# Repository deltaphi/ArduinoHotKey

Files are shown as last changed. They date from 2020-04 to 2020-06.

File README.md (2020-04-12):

# ArduinoHotKey - An Arduino-Based USB Hotkey-Keyboard

This project started because I needed a dedicated button to mute/unmute myself in Voicecalls.
Mute/Unmute functionality is avilable as a Hotkey-Combination, but why pressm ore buttons than necessary?
This project will let you use an Arduino with an Atmega32u4 Processor (e.g., Arduino Pro Micro) to sond arbitrary Key sequences to a USB host device (such as your PC or Mac).
It can send all key sequences that the Arduino Keyboard Library can produce.

## Software

A simple Arduino sketch that can read a number of digital inputs and procude arbitrary key sequences on button press.
Customize the Code to configure the key sequence of your needs.

## Hardware

A simple PCB based around a bunch of Cherry MX PCB-mount switches and an Arduino Pro Micro. Includes Hardware-Deboundinc to be extra-fancy.

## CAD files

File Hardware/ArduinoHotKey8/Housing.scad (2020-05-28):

$fn=50;

wall_thickness = 2; // Should be a multiple of 0.4
fit_tolerance = 0.2;
rotate_angle=-10;

standoff_wall_thickness = 1.6; // Should be a multiple of 0.4.
standoff_inner_diameter = 2.8; // 2,5 when tapping for M3 with extra gear.
standoff_screw_diameter = 6; // Extra space to sink the screw into.
standoff_screw_passthrough_diameter = 3.6; // 3.2 minimum when not tapping.
screw_length = 10;

hole_to_side = 5.08; // Value tested OK

pcb_width = 96.52;
pcb_depth = 77.47;
pcb_thickness = 2;
pcb_side_fit_tolerance = 1;

pcb_front_outer_distance = 5; // 13
pcb_front_inner_distance = pcb_front_outer_distance - wall_thickness;

housing_width = pcb_width + (2*(pcb_side_fit_tolerance + wall_thickness));

housing_depth = pcb_depth + (2*(pcb_side_fit_tolerance + wall_thickness));

pcb_back_inner_distance = 18; // Value tested OK
pcb_back_outer_distance = pcb_back_inner_distance + wall_thickness;

lip_height = pcb_thickness + fit_tolerance;
lip_width = (wall_thickness / 2) - (fit_tolerance / 2);

// Distance from the top
switch_y1 = 33.02; // Value tested OK
switch_y2 = 58.42; // Value tested OK

// Distance from the left
switch_x1 = 10.16; // Value tested OK
switch_x2 = 35.56; // Value tested OK
switch_x3 = 60.96; // Value tested OK
switch_x4 = 86.36; // Value tested OK

// Standoffs

// * Dimenstions
standoff_outer_diameter = standoff_inner_diameter + (2*standoff_wall_thickness);
standoff_outer_screw_diameter = standoff_screw_diameter + (2*standoff_wall_thickness);
standoff_screwhole_diameter = standoff_screw_passthrough_diameter + (2*standoff_wall_thickness);

// * locations in top and bottom
standoff_x1 = wall_thickness + pcb_side_fit_tolerance + hole_to_side;
standoff_x2 = wall_thickness + pcb_side_fit_tolerance + pcb_depth - hole_to_side;

standoff_y1 = wall_thickness + pcb_side_fit_tolerance + hole_to_side;
standoff_y2 = wall_thickness + pcb_side_fit_tolerance + pcb_width - hole_to_side;

// * Module in the bottom case
module standoff_bottom(x,y) {
   
    // Leave 1mm space in the top screw holes
    standoff_bottom_screw_length = screw_length - pcb_thickness - pcb_front_outer_distance + 1;
    standoff_screw_head_height = pcb_back_inner_distance - standoff_bottom_screw_length;
   
    difference() {
        // Solid part
        union() {
            // Screw head part. Should leave standoff_bottom_screw_length - wall_thickness for the following thin part.
            translate([x, y ,0]) cylinder(h=standoff_screw_head_height + wall_thickness,d=standoff_outer_screw_diameter);
            // Screw part
            translate([x, y ,0]) cylinder(h=pcb_back_outer_distance,d=standoff_screwhole_diameter);
        }
       
        // Take away the holes
       
        // Screw head hole part.
        translate([x, y ,-0.1]) cylinder(h=standoff_screw_head_height,d=standoff_screw_diameter);
       
        // Screw hole part
        translate([x, y ,-0.1]) cylinder(h=pcb_back_outer_distance+1,d=standoff_screw_passthrough_diameter);
    }
}

// * Module in the top case
module standoff_top(x,y,height) {
    difference() {
        translate([x, y ,0]) cylinder(h=height,d=standoff_outer_diameter);
        translate([x, y ,-0.1]) cylinder(h=height+1,d=standoff_inner_diameter);
    }
}






// Basic Bottom
module bottomcase() {
difference() {
    union() {
        difference() {
    
            union() {
                // Main wall
                rotate(a=rotate_angle,v=[0,1,0]) cube([housing_depth, housing_width, pcb_back_outer_distance]);
                    
                // Inner lip
                rotate(a=rotate_angle,v=[0,1,0])translate([lip_width, lip_width, 0]) cube([housing_depth - 2*lip_width, housing_width - 2*lip_width, pcb_back_outer_distance+lip_height]);
                
            }
                
            // Inner space
            rotate(a=rotate_angle,v=[0,1,0])translate([wall_thickness,wall_thickness,wall_thickness])
            cube([pcb_depth + (2*pcb_side_fit_tolerance), pcb_width + (2*pcb_side_fit_tolerance),pcb_back_inner_distance+lip_height+1]);
               
            // Hole for USB wire
            rotate(a=rotate_angle,v=[0,1,0])translate([62+wall_thickness,0,10+wall_thickness])
            rotate([90,90,0])
            cylinder(h=wall_thickness*3, d=12, center=true);
    
            rotate(a=rotate_angle,v=[0,1,0])translate([62+wall_thickness,0,18+wall_thickness])
            cube([12,wall_thickness*3,12+lip_height], center = true);
               
    
        }
        // add Standoffs
        rotate(a=rotate_angle,v=[0,1,0])standoff_bottom(standoff_x1, standoff_y1);
        rotate(a=rotate_angle,v=[0,1,0])standoff_bottom(standoff_x2, standoff_y1);
        rotate(a=rotate_angle,v=[0,1,0])standoff_bottom(standoff_x1, standoff_y2);
        rotate(a=rotate_angle,v=[0,1,0])standoff_bottom(standoff_x2, standoff_y2);
        //add bottom layer
        translate([0,0,-1]) cube([housing_depth, housing_width, pcb_back_outer_distance-7]);
    }
    translate([-10,-10,-2]) cube([housing_depth+20, housing_width+20, pcb_back_outer_distance-7]);
    rotate(a=rotate_angle,v=[0,1,0]) translate([-10,-10,-
    5]) cube([housing_depth+20, housing_width+20, 5]);
            // add holes from the bottom
            rotate(a=rotate_angle,v=[0,1,0])translate([standoff_x1, standoff_y1 ,-0.1]) cylinder(d=standoff_screw_diameter, h=10+wall_thickness);
            rotate(a=rotate_angle,v=[0,1,0])translate([standoff_x2, standoff_y1 ,-0.1]) cylinder(d=standoff_screw_diameter, h=10+wall_thickness);
            rotate(a=rotate_angle,v=[0,1,0])translate([standoff_x1, standoff_y2 ,-0.1]) cylinder(d=standoff_screw_diameter, h=10+wall_thickness);
            rotate(a=rotate_angle,v=[0,1,0])translate([standoff_x2, standoff_y2 ,-0.1]) cylinder(d=standoff_screw_diameter, h=10+wall_thickness);
    }
}



// Solid switch cube. Can be used to subtract from cubes to punch correct-sized holes.
// Designed so that the center plane represents the top of the case.
// Adds a recess so that the plate thickness around the switch is limited.
module switch() {
    switch_hole_side = 14;// Value tested correctly for Cherry MX
    switch_plate_thickness = 1.5;
   
    spacer_side = switch_hole_side + 2; // 1mm all round
   
   
    translate([-switch_hole_side/2,-switch_hole_side/2,-1]) cube([switch_hole_side, switch_hole_side, wall_thickness+2]);
    translate([-spacer_side/2,-spacer_side/2,switch_plate_thickness]) cube([spacer_side,spacer_side,wall_thickness+2]);
}

// switch();

module switcharray() {
    translate([switch_y1, switch_x1, 0]) switch();
    translate([switch_y1, switch_x2, 0]) switch();
    translate([switch_y1, switch_x3, 0]) switch();
    translate([switch_y1, switch_x4, 0]) switch();
           
    translate([switch_y2, switch_x1, 0]) switch();
    translate([switch_y2, switch_x2, 0]) switch();
    translate([switch_y2, switch_x3, 0]) switch();
    translate([switch_y2, switch_x4, 0]) switch();
}

// Basic top
module topcase() {

    difference() {

        // Main wall with added height for lip
        cube([housing_depth, housing_width, pcb_front_outer_distance + lip_height]);
           
        // Carve out interior
        translate([wall_thickness, wall_thickness, wall_thickness])
        cube([pcb_depth + (2*pcb_side_fit_tolerance), pcb_width + (2*pcb_side_fit_tolerance), pcb_front_inner_distance+2]);

        // Carve out lip
        translate([lip_width, lip_width, pcb_front_outer_distance])
        cube([housing_depth - 2*lip_width, housing_width - 2*lip_width, pcb_front_inner_distance+2]);

        // Carve out switch holes
        translate([wall_thickness+pcb_side_fit_tolerance, wall_thickness+pcb_side_fit_tolerance, 0]) switcharray();
    }

    // Standoffs
    translate([0,0,wall_thickness-0.1]) standoff_top(standoff_x1, standoff_y1, pcb_front_inner_distance+0.1);
    translate([0,0,wall_thickness-0.1]) standoff_top(standoff_x2, standoff_y1, pcb_front_inner_distance+0.1);
    translate([0,0,wall_thickness-0.1]) standoff_top(standoff_x1, standoff_y2, pcb_front_inner_distance+0.1);
    translate([0,0,wall_thickness-0.1]) standoff_top(standoff_x2, standoff_y2, pcb_front_inner_distance+0.1);
}

module all() {
    translate([-100,0,0]) bottomcase();
    translate([20,0,0]) topcase();
}

all();

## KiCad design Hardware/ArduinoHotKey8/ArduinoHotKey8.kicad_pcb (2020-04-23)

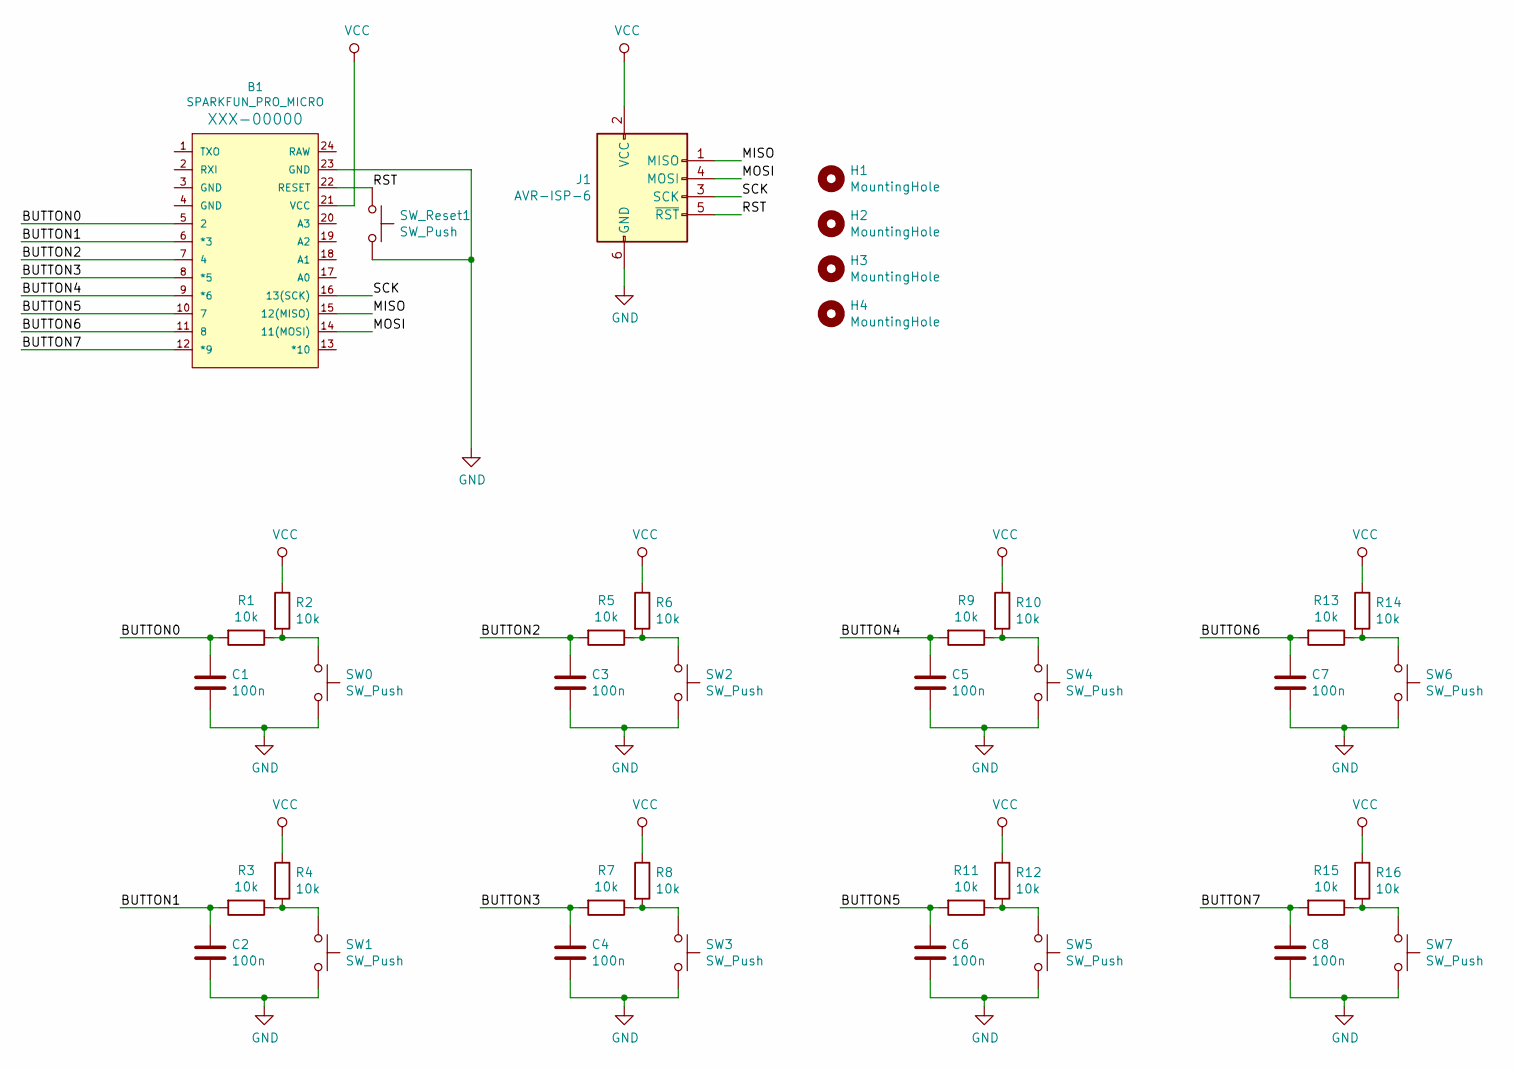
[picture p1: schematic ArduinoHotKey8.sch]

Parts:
B1: SPARKFUN_PRO_MICRO
C1, C2, C3, C4, C5, C6, C7, C8: 100n; C_Disc_D3.0mm_W1.6mm_P2.50mm
H1, H2, H3, H4: MountingHole; MountingHole_3.2mm_M3
J1: AVR-ISP-6; IDC-Header_2x03_P2.54mm_Vertical
R1, R2, R3, R4, R5, R6, R7, R8, R9, R10, R11, R12, R13, R14, R15, R16: 10k; R_Axial_DIN0207_L6.3mm_D2.5mm_P10.16mm_Horizontal
SW0, SW1, SW2, SW3, SW4, SW5, SW6, SW7: SW_Push; SW_Cherry_MX_1.00u_PCB
SW_Reset1: SW_Push; SW_PUSH_6mm

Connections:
/BUTTON0: B1.5 (2), C1.1, R1.2
/BUTTON1: B1.6 (*3), C2.1, R3.2
/BUTTON2: B1.7 (4), C3.1, R5.2
/BUTTON3: B1.8 (*5), C4.1, R7.2
/BUTTON4: B1.9 (*6), C5.1, R9.2
/BUTTON5: B1.10 (7), C6.1, R11.2
/BUTTON6: B1.11 (8), C7.1, R13.2
/BUTTON7: B1.12 (*9), C8.1, R15.2
/MISO: B1.15 (12(MISO)), J1.1 (MISO)
/MOSI: B1.14 (11(MOSI)), J1.4 (MOSI)
/RST: B1.22 (RESET), J1.5 (~RST), SW_Reset1.1
/SCK: B1.16 (13(SCK)), J1.3 (SCK)
GND: B1.23 (GND), C1.2, C2.2, C3.2, C4.2, C5.2, C6.2, C7.2, C8.2, J1.6 (GND), SW0.2, SW1.2, SW2.2, SW3.2, SW4.2, SW5.2, SW6.2, SW7.2, SW_Reset1.2
unnamed: R1.1, R2.2, SW0.1
unnamed: R3.1, R4.2, SW1.1
unnamed: R5.1, R6.2, SW2.1
unnamed: R7.1, R8.2, SW3.1
unnamed: R9.1, R10.2, SW4.1
unnamed: R11.1, R12.2, SW5.1
unnamed: R13.1, R14.2, SW6.1
unnamed: R15.1, R16.2, SW7.1
VCC: B1.21 (VCC), J1.2 (VCC), R2.1, R4.1, R6.1, R8.1, R10.1, R12.1, R14.1, R16.1

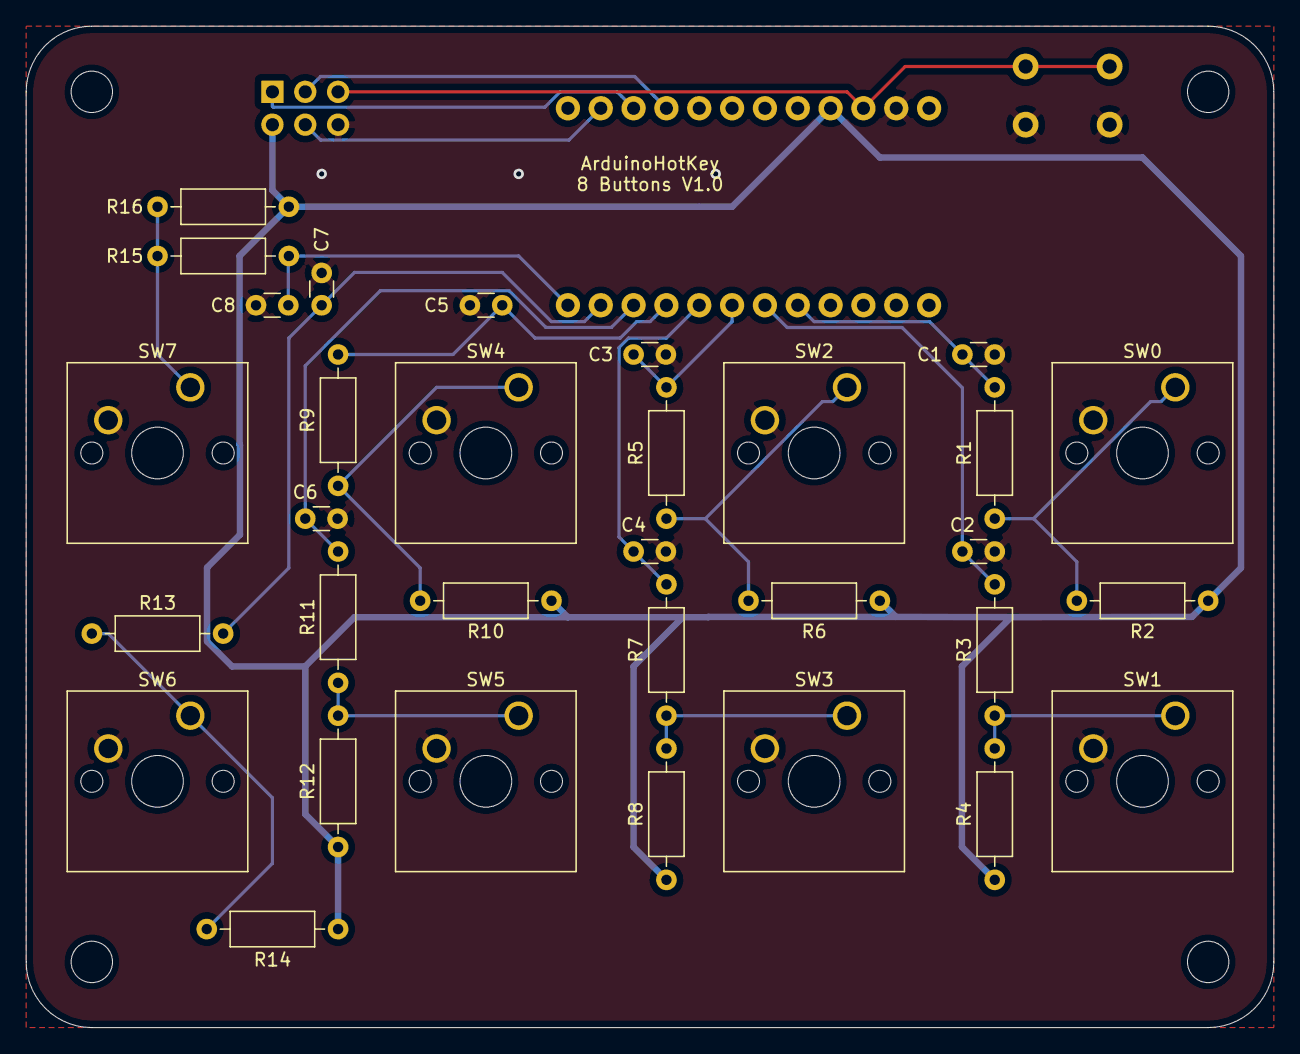
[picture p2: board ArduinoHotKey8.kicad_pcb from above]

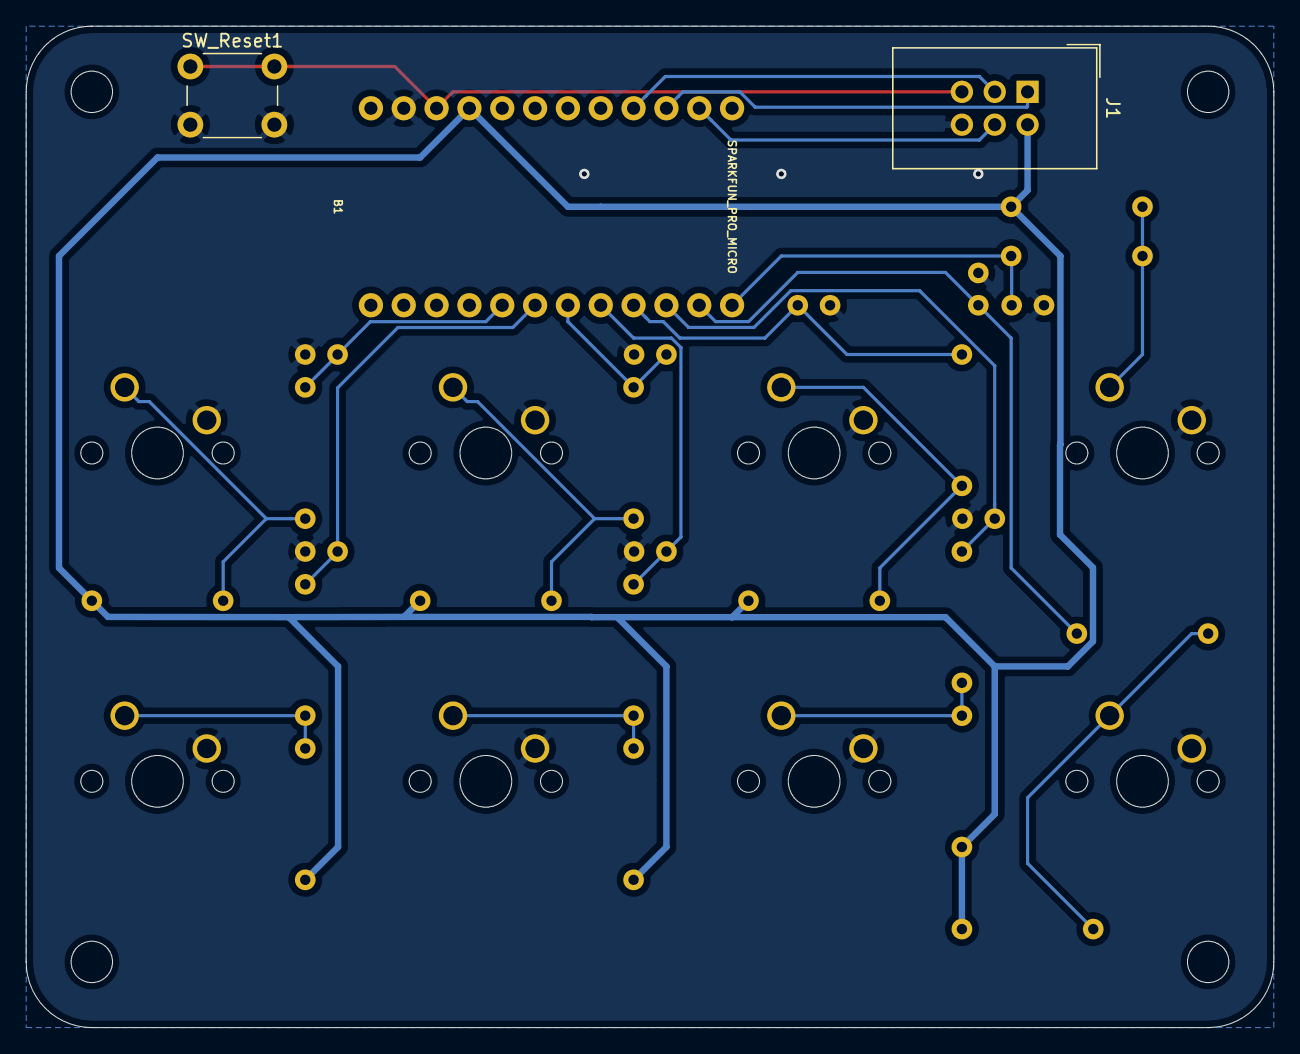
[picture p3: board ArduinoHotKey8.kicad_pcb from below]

Board: 2 copper layers, 96.5 x 77.5 mm, 39 parts (3 on the bottom side), 22 nets.

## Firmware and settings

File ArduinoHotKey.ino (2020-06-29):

/*
 * ArduinoHotKey Sketch.
 * 
 * Hotkey-Keyboard for up to 8 Buttons on an Arduino Pro Nano (Atmega32)
 * 
 * Requires the HID-Project library:
 *  https://www.arduinolibraries.info/libraries/hid-project
 *  
 */

#include "HID-Project.h"

// -------------------------
// Tweak your paramters here
// -------------------------

#define NUM_BUTTONS (8)
#define BUTTON_INDEX_OFFSET (2)
#define BUTTON_DISTANCE (1)

#define BUTTON_PRESSED(x) (x == LOW)

#define USE_SERIAL_DEBUG (0)

// ----------------------------------------------------------
// Stop Tweaking paramters here and continue tweaking actions
// below.
// ----------------------------------------------------------


uint8_t buttonState[NUM_BUTTONS];

constexpr uint8_t buttonIndexToPin(const uint8_t buttonIndex) {
  return BUTTON_INDEX_OFFSET + (BUTTON_DISTANCE * buttonIndex);
}

void setup() {
#if (USE_SERIAL_DEBUG == 1)
  Serial.begin(115200);
  Serial.println("ArduinoHotKey ready.");
#endif
  
  // Start Keyboard library
  Consumer.begin(); // Media Keys
  Keyboard.begin(); // 'regular' Boot Keyboard

  // Configure all IO pins.
  for (uint8_t i = 0; i < NUM_BUTTONS; ++i) {
    buttonState[i] = HIGH;
    pinMode(buttonIndexToPin(i), INPUT);
  }

}

void releaseAllWithDelay() {
  delay(100);
  Keyboard.releaseAll();
}

void singleButton(uint8_t keyValue, uint8_t keyCode) {
  if (BUTTON_PRESSED(keyValue)) {
    Keyboard.press(keyCode);
  } else {
    Keyboard.release(keyCode);
  }
}

void singleButtonConsumer(uint8_t keyValue, uint8_t keyCode) {
  if (BUTTON_PRESSED(keyValue)) {
    Consumer.press(keyCode);
  } else {
    Consumer.release(keyCode);
  }
}

/**
 * \brief Add processing for actual button presses here.
 * \param buttonIndex The number of the button that was pressed/released.
 * \param buttonValue LOW when the button was pressend, HIGH when the button is released.
 */
void processEdge(uint8_t buttonIndex, uint8_t buttonValue) {
#if (USE_SERIAL_DEBUG == 1)
  Serial.print(F("Button "));
  Serial.print(buttonIndex);
  Serial.print(F(" was "));
  if (BUTTON_PRESSED(buttonValue)) {
    Serial.println(F("pressed."));
  } else {
    Serial.println(F("released."));  
  }  
#endif


// -------------------------
// Tweak your actions here
// -------------------------

  switch (buttonIndex) {
    /* Top row */
    case 7:
      singleButtonConsumer(buttonValue, MEDIA_PREVIOUS);
      break;
    case 4:
      singleButtonConsumer(buttonValue, MEDIA_STOP);
      break;
    case 2:
      singleButtonConsumer(buttonValue, MEDIA_PLAY_PAUSE);
      break;
    case 0:
      singleButtonConsumer(buttonValue, MEDIA_NEXT);
      break;

    /* Bottom Row */
    case 6:
      if (BUTTON_PRESSED(buttonValue)) {
        // button pressed
        // Skype Global Mute/Unmute Hotkey
        Keyboard.press(KEY_LEFT_GUI);
        Keyboard.press(KEY_F4);
        releaseAllWithDelay();
      }
      break;
    case 5:
      if (BUTTON_PRESSED(buttonValue)) {
        // Microsoft Teams Global Mute/Unmute Hotkey
        Keyboard.press(KEY_LEFT_CTRL);
        Keyboard.press(KEY_LEFT_SHIFT);
        Keyboard.press(KEY_M);
        releaseAllWithDelay();
      }
      break;

    case 3:
      // Volume Down
      singleButtonConsumer(buttonValue, MEDIA_VOL_DOWN);
      break;
      
    case 1:
      // Volume Up
      singleButtonConsumer(buttonValue, MEDIA_VOL_UP);
  }
  // -------------------------------
  // Stop tweaking your actions here
  // -------------------------------
}

void loop() {
  // Iterate all configured IO pins.
  for (uint8_t i = 0; i < NUM_BUTTONS; ++i) {
    // Read pin value.
    uint8_t value = digitalRead(buttonIndexToPin(i));
    if (value != buttonState[i]) {
      // On state change, perform an action.
      processEdge(i, value);
      buttonState[i] = value;
    }
  }
}

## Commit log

2020-04-12 Create ArduinoHotKey.ino
    Initial prototype Sketch for a single button.
2020-04-12 Create .gitignore
    Added .gitignore for KiCAD projects.
2020-04-12 Update ArduinoHotKey.ino
    Converted to 4-button sketch with non-identical button mapping.
    Made release delay configurable.
2020-04-12 Added empty 8-Button PCB.
    [ArduinoHotKey8.kicad_pcb, ArduinoHotKey8.sch]
2020-04-12 Added ProMini Board
    * Added Sparkfun Libraries for Arduino Pro Mini footprint.
    * Added initial project with a single Arduino board in it.
    [ArduinoHotKey8.sch]
2020-04-12 Compleded Circuit
    [ArduinoHotKey8.sch]
2020-04-12 First large PCB Design
    [ArduinoHotKey8.kicad_pcb, ArduinoHotKey8.sch]
2020-04-12 Update ArduinoHotKey8.kicad_pcb
    Fixed missing infill
    [ArduinoHotKey8.kicad_pcb]
2020-04-13 Added ISP Header
    Added ISP Header and moved bulky parts to the back
    [ArduinoHotKey8.kicad_pcb, ArduinoHotKey8.sch]
2020-04-13 Update ArduinoHotKey8.kicad_pcb
    Added Label
    [ArduinoHotKey8.kicad_pcb]
2020-04-13 Rearranged labels
    [ArduinoHotKey8.kicad_pcb]
2020-04-13 Minor improvement for USB connector
    [ArduinoHotKey8.kicad_pcb]
2020-04-13 Layout optimizations for USB Port
    [ArduinoHotKey8.kicad_pcb]
2020-04-23 Update ArduinoHotKey.ino
    Reconfigure for ArduinoHotKey8 board.
2020-04-26 Attempts at a housing with OpenSCAD
    [Housing.scad]
2020-04-27 Update Housing.scad
    Small fixes
    [Housing.scad]
2020-04-27 Update Housing.scad
    Added switch locations
    [Housing.scad]
2020-04-27 Improved screw-through standoffs
    [Housing.scad]
2020-04-27 Added front with switch holes
    [Housing.scad]
2020-04-27 Standoffs for the bottom done
    [Housing.scad]
2020-04-27 Fixed top standoff location
    [Housing.scad]
2020-04-27 Fixed all standoffs
    [Housing.scad]
2020-04-27 Added lip to bottom case
    [Housing.scad]
2020-04-27 Lips for bottom case
    And proper computation of lips
    [Housing.scad]
2020-04-27 Use computed sizes
    [Housing.scad]
2020-04-28 Adjust lip height to accomodate the PCB
    [Housing.scad]
2020-04-28 Fix length of bottom standoffs
    [Housing.scad]
2020-05-01 Fix first batch of errors spottet from prototype.
    [Housing.scad]
2020-05-05 More measurements and tolerances fixed.
    [Housing.scad]
2020-05-07 Added plastic for the screw head to rest on
    [Housing.scad]
2020-05-07 Fixed diameter of bottom screw hole
    [Housing.scad]
2020-05-07 Reenable topcase
    [Housing.scad]
2020-05-09 Fixed Standoff locations
    [Housing.scad]
2020-05-24 Switched to HID-Proejct library.
    Added support for Multimedia Keys.
2020-05-28 Added angled bottom case
    [Housing.scad]
2020-06-27 Move Sketch file.
    Sketch file places to that the repostory can directly be checked out
    into the Arduino IDE.
